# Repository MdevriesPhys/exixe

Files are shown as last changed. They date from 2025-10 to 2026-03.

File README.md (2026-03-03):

# exixe: Low-cost miniature Nixie tube driver modules

[Get exixe](https://www.tindie.com/products/dekuNukem/exixe-miniture-nixie-tube-driver-modules/) | [User manual](getting_started.md)









Forked from original dekuNukem repo, some modifications to boards and firmware.

exixe is a miniature driver module for IN-12 and IN-14 Nixie tubes.

It aims to simplify Nixie tube related projects by eliminating the need for obscure vintage driver chips and multiplexing circuits. Instead, you can control every digit and the RGB backlight via SPI using only 3 wires and 1 line of code.

exixe is cheap, small and modular for easy integration. It is compatible with Arduino, Raspberry Pi, and virtually all embedded dev boards today.

## Updated firmware 2026-03-03
Original firmware for IN-14 boards had an issue where the LEDs would be slightly on when set to 0 brightness. This has been updating in exixie14.hex firmware. See [Getting started](getting_started.md) for information about reflashing.

## Buy exixe on Tindie!

I did a small production run of exixe modules, and now you can buy them directly on Tindie:

https://www.tindie.com/products/dekuNukem/exixe-miniture-nixie-tube-driver-modules/

## Features

Compared to the traditional approach, exixe modules offers significant advantages:

#### Small and modular
* 2x4 cm (0.79x1.57 inches)
* Breadboard friendly
* Easy integration
* Reusable

#### SPI interface
* High speed, up to 24MHz SCLK
* Simple 16-byte command packet
* Available on virtually all embedded systems including Arduino and Raspberry Pi

#### Advanced control
* RGB backlight
* 128 brightness levels
* Hardware PWM on all cathodes and LEDs for smooth dimming and animations

#### Tube overdrive
* Optionally allows twice the cathode current
* For poisoned cathodes in second-hand tubes
* [Before](resources/no_overdrive.jpg) and [after](resources/with_overdrive.jpg).

#### No multiplexing
* Brighter display
* Longer tube life
* Simpler design
* Lower power consumption

## Getting started

Please see [getting_started.md](/getting_started.md)

## Arduino Library

Please [click here](arduino_library)

## Raspberry Pi/Python Library

Please [click here](python_library)

## Pinout, SPI command format and technical details

Please see [technical_details.md](/technical_details.md)

## Supported tubes

exixe-14 module is primarily designed for IN-14 Nixie tubes, but will also work with IN-16 and IN-19 tubes. IN-19 specific board in development.

exixe-12 module is primarily designed for IN-12 Nixie tubes, but works with IN-15 tubes as well.

## Using other tubes

You can also use exixe module with unsupported tubes, with some modification.

Please see [unsupported_tubes.md](/unsupported_tubes.md)

## Making some yourself

Please see [making_some.md](/making_some.md)

## Contact

Questions? Feel free to [open an issue](https://github.com/dekuNukem/exixe/issues). This is the preferred way since it helps other people too.

You can also email me at `dekunukem gmail com` for inquires.

## More photos

exixe-12 working with an Arduino Micro, showing a smooth crossfade animation:



exixe-14 in action on a [finished clock](https://github.com/dekuNukem/exixe_clock):





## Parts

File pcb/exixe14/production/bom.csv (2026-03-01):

Designator | Footprint | Quantity | Value | LCSC Part #
C1, C2, C3 | 0805 | 3 | 100n
D1 | LED_RGB_Wuerth-PLCC4_3.2x2.8mm_150141M173100 | 1 | LED_ABRG
J1, J2 | PinHeader_1x07_P2.54mm_Vertical | 2 | Conn_01x07
N1 | IN-14 | 1 | IN-14
Q1 | SOT-323_SC-70 | 1 | Q_PNP_BEC
Q10, Q11, Q12, Q13, Q14, Q2, Q3, Q4, Q5, Q6, Q7, Q8, Q9 | SOT-323_SC-70 | 13 | Q_NPN_BEC
R1, R10, R14, R15, R16, R17, R18, R19, R2, R20, R21, R22, R23, R24, R25, R5, R7, R8 | 0805 | 18 | 10k
R11, R3 | 0805 | 2 | 68k
R12 | 0805 | 1 | 680R
R13, R9 | 0805 | 2 | 330R
R4, R6 | 0805 | 2 | 1M
U1 | LQFP-32_7x7mm_P0.8mm | 1 | STM32F042K6Tx

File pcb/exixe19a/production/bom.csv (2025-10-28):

Designator | Footprint | Quantity | Value | LCSC Part #
C1, C2, C3 | 0805 | 3 | 100n
D1 | LED_RGB_Wuerth-PLCC4_3.2x2.8mm_150141M173100 | 1 | LED_ABRG
Q1, Q10, Q11, Q4, Q5, Q6, Q7, Q8, Q9 | SOT-323_SC-70 | 9 | BF820W
Q3 | SOT-323_SC-70 | 1 | MSB92W
R1, R13, R14, R15, R16, R17, R18, R19, R2, R20, R21, R3, R4, R5 | 0805 | 14 | 10k
R10 | 0805 | 1 | 680R
R11, R12 | 0805 | 2 | 330R
R6, R7 | 0805 | 2 | 1M
R8, R9 | 0805 | 2 | 68k
U1 | TQFP-32_7x7mm_P0.8mm | 1 | STM32F042K6

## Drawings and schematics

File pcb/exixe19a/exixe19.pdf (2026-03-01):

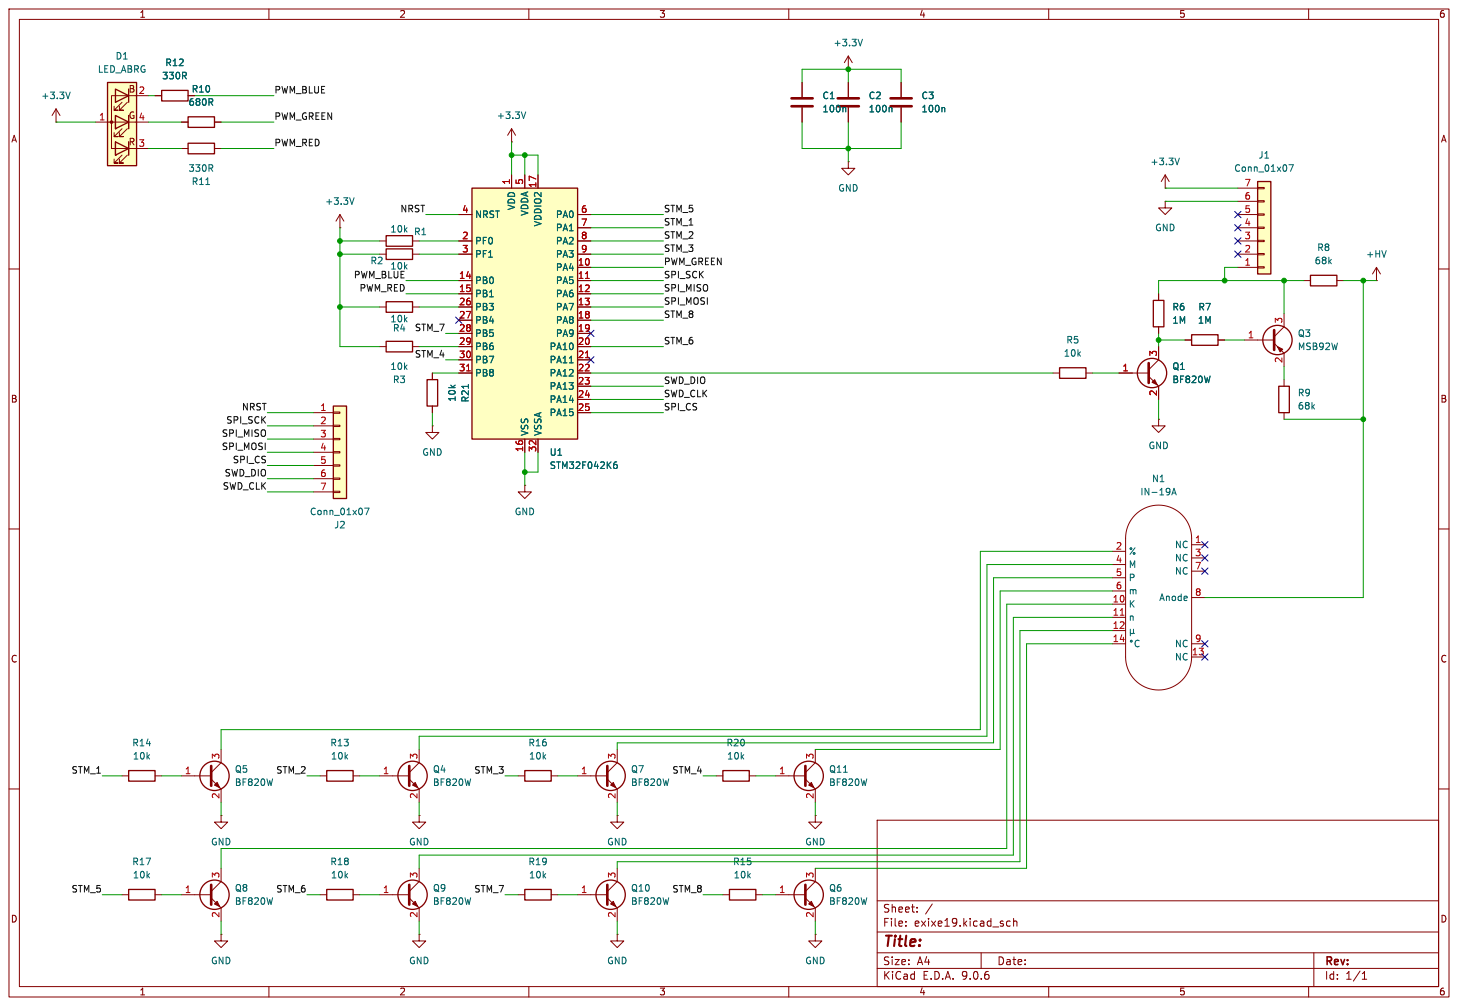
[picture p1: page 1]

Id: 1/1 Title: File: exixe19.kicad_sch Sheet: / 1

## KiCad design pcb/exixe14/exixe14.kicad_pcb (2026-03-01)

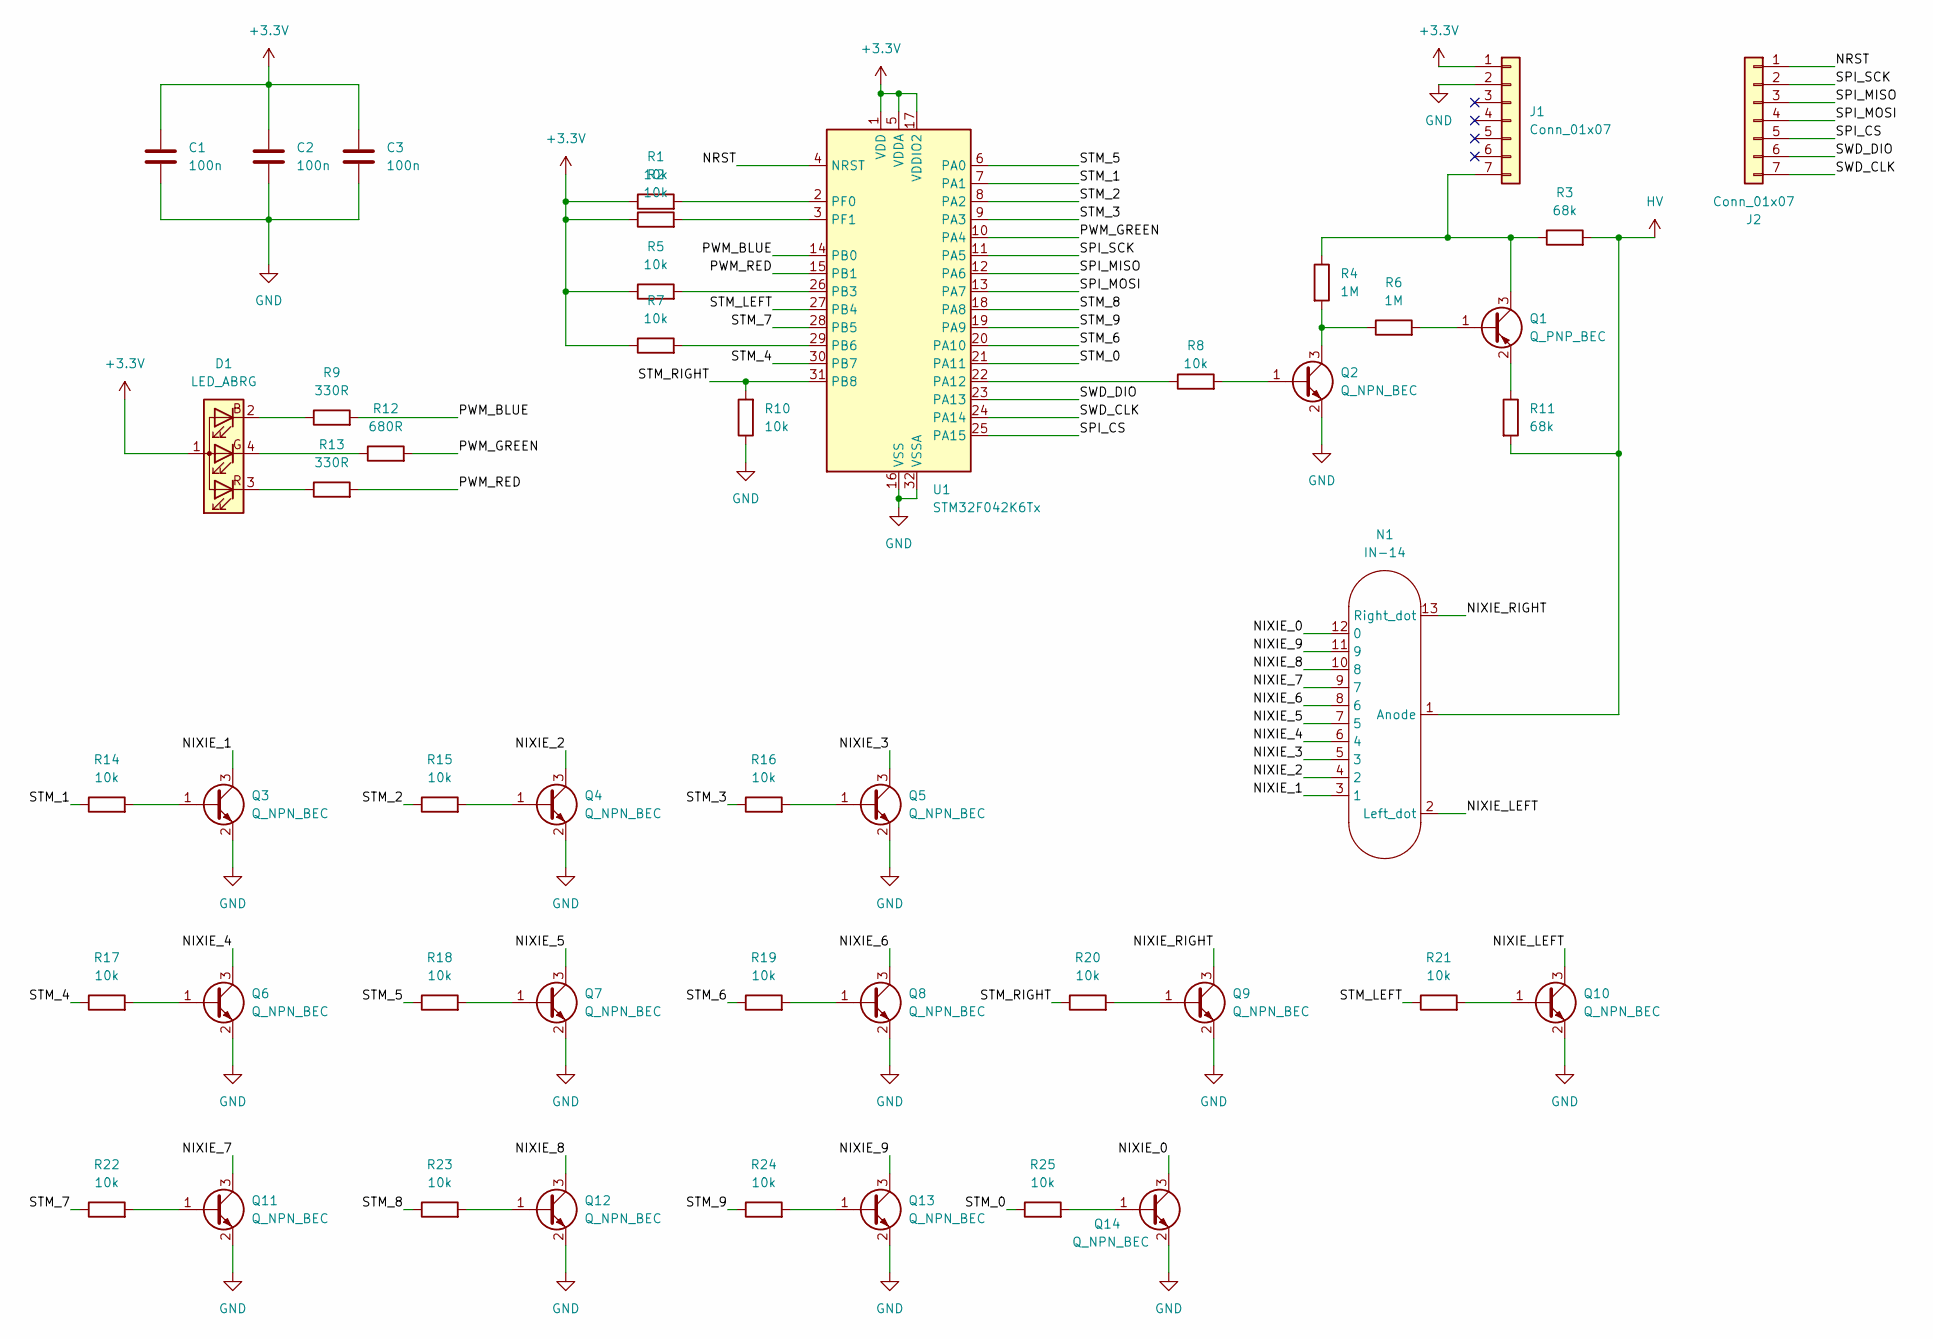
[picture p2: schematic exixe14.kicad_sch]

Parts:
C1, C2, C3: 100n; C_0805_2012Metric
D1: LED_ABRG; LED_RGB_Wuerth-PLCC4_3.2x2.8mm_150141M173100
J1, J2: Conn_01x07; PinHeader_1x07_P2.54mm_Vertical
N1: IN-14
Q1: Q_PNP_BEC; SOT-323_SC-70
Q2, Q3, Q4, Q5, Q6, Q7, Q8, Q9, Q10, Q11, Q12, Q13, Q14: Q_NPN_BEC; SOT-323_SC-70
R1, R2, R5, R7, R8, R10, R14, R15, R16, R17, R18, R19, R20, R21, R22, R23, R24, R25: 10k; R_0805_2012Metric
R3, R11: 68k; R_0805_2012Metric
R4, R6: 1M; R_0805_2012Metric
R9, R13: 330R; R_0805_2012Metric
R12: 680R; R_0805_2012Metric
U1: STM32F042K6Tx; LQFP-32_7x7mm_P0.8mm

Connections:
+3.3V: C1.1, C2.1, C3.1, D1.1 (A), J1.1, R1.1, R2.1, R5.1, R7.1, U1.1 (VDD), U1.5 (VDDA), U1.17 (VDDIO2)
/NIXIE_0: N1.12 (0), Q14.3 (C)
/NIXIE_1: N1.3 (1), Q3.3 (C)
/NIXIE_2: N1.4 (2), Q4.3 (C)
/NIXIE_3: N1.5 (3), Q5.3 (C)
/NIXIE_4: N1.6 (4), Q6.3 (C)
/NIXIE_5: N1.7 (5), Q7.3 (C)
/NIXIE_6: N1.8 (6), Q8.3 (C)
/NIXIE_7: N1.9 (7), Q11.3 (C)
/NIXIE_8: N1.10 (8), Q12.3 (C)
/NIXIE_9: N1.11 (9), Q13.3 (C)
/NIXIE_LEFT: N1.2 (Left_dot), Q10.3 (C)
/NIXIE_RIGHT: N1.13 (Right_dot), Q9.3 (C)
/NRST: J2.1, U1.4 (NRST)
/PWM_BLUE: R9.2, U1.14 (PB0)
/PWM_GREEN: R12.2, U1.10 (PA4)
/PWM_RED: R13.2, U1.15 (PB1)
/SPI_CS: J2.5, U1.25 (PA15)
/SPI_MISO: J2.3, U1.12 (PA6)
/SPI_MOSI: J2.4, U1.13 (PA7)
/SPI_SCK: J2.2, U1.11 (PA5)
/STM_0: R25.1, U1.21 (PA11)
/STM_1: R14.1, U1.7 (PA1)
/STM_2: R15.1, U1.8 (PA2)
/STM_3: R16.1, U1.9 (PA3)
/STM_4: R17.1, U1.30 (PB7)
/STM_5: R18.1, U1.6 (PA0)
/STM_6: R19.1, U1.20 (PA10)
/STM_7: R22.1, U1.28 (PB5)
/STM_8: R23.1, U1.18 (PA8)
/STM_9: R24.1, U1.19 (PA9)
/STM_LEFT: R21.1, U1.27 (PB4)
/STM_RIGHT: R10.2, R20.1, U1.31 (PB8)
/SWD_CLK: J2.7, U1.24 (PA14)
/SWD_DIO: J2.6, U1.23 (PA13)
GND: C1.2, C2.2, C3.2, J1.2, Q2.2 (E), Q3.2 (E), Q4.2 (E), Q5.2 (E), Q6.2 (E), Q7.2 (E), Q8.2 (E), Q9.2 (E), Q10.2 (E), Q11.2 (E), Q12.2 (E), Q13.2 (E), Q14.2 (E), R10.1, U1.16 (VSS), U1.32 (VSSA)
HV: N1.1 (Anode), R3.2, R11.2
unnamed: D1.2 (BK), R9.1
unnamed: D1.4 (GK), R12.1
unnamed: D1.3 (RK), R13.1
unnamed: J1.7, Q1.3 (C), R3.1, R4.1
unnamed: Q1.1 (B), R6.2
unnamed: Q1.2 (E), R11.1
unnamed: Q2.1 (B), R8.2
unnamed: Q2.3 (C), R4.2, R6.1
unnamed: Q3.1 (B), R14.2
unnamed: Q4.1 (B), R15.2
unnamed: Q5.1 (B), R16.2
unnamed: Q6.1 (B), R17.2
unnamed: Q7.1 (B), R18.2
unnamed: Q8.1 (B), R19.2
unnamed: Q9.1 (B), R20.2
unnamed: Q10.1 (B), R21.2
unnamed: Q11.1 (B), R22.2
unnamed: Q12.1 (B), R23.2
unnamed: Q13.1 (B), R24.2
unnamed: Q14.1 (B), R25.2
unnamed: R8.1, U1.22 (PA12)
unnamed: R5.2, U1.26 (PB3)
unnamed: R7.2, U1.29 (PB6)
unnamed: R1.2, U1.2 (PF0)
unnamed: R2.2, U1.3 (PF1)

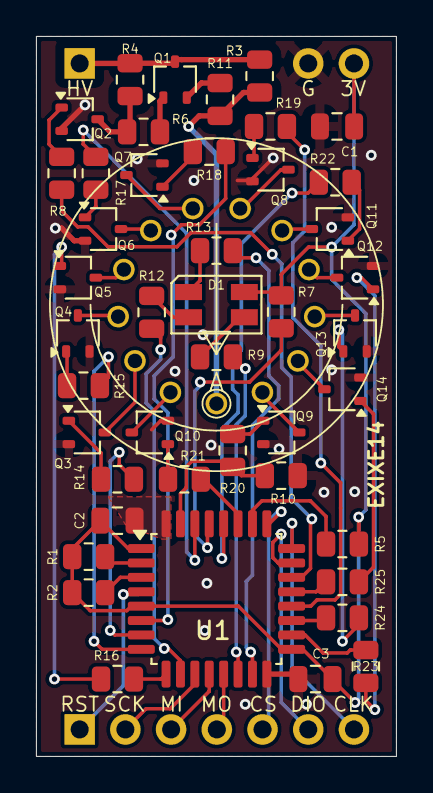
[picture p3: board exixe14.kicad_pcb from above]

Board: 2 copper layers, 20.0 x 40.0 mm, 47 parts (0 on the bottom side), 62 nets.

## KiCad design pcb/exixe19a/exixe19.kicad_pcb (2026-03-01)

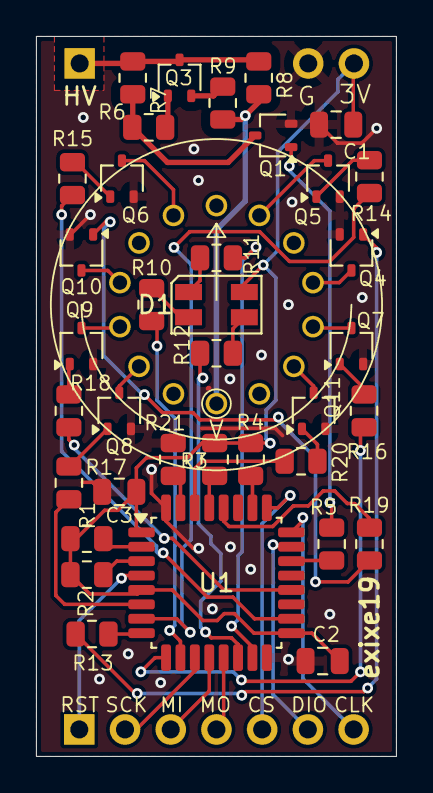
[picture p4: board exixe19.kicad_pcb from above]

Board: 2 copper layers, 20.0 x 40.0 mm, 39 parts (0 on the bottom side), 51 nets.

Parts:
C1, C2, C3: 100n; C_0805_2012Metric
D1: LED_ABRG; LED_RGB_Wuerth-PLCC4_3.2x2.8mm_150141M173100
J1: Conn_01x07; PinHeader_1x07_P2.54mm_Vertical_special
J2: Conn_01x07; PinHeader_1x07_P2.54mm_Vertical
N1: IN-19A
Q1, Q4, Q5, Q6, Q7, Q8, Q9, Q10, Q11: BF820W; SOT-323_SC-70
Q3: MSB92W; SOT-323_SC-70
R1, R2, R3, R4, R5, R13, R14, R15, R16, R17, R18, R19, R20, R21: 10k; R_0805_2012Metric
R6, R7: 1M; R_0805_2012Metric
R8, R9: 68k; R_0805_2012Metric
R10: 680R; R_0805_2012Metric
R11, R12: 330R; R_0805_2012Metric
U1: STM32F042K6; TQFP-32_7x7mm_P0.8mm

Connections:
+3.3V: C1.1, C2.1, C3.1, D1.1 (A), J1.7, R1.1, R2.1, R3.1, R4.1, U1.1 (VDD), U1.5 (VDDA), U1.17 (VDDIO2)
+HV: N1.8 (Anode), R8.1, R9.1
/NRST: J2.1, U1.4 (NRST)
/PWM_BLUE: R12.2, U1.14 (PB0)
/PWM_GREEN: R10.2, U1.10 (PA4)
/PWM_RED: R11.2, U1.15 (PB1)
/SPI_CS: J2.5, U1.25 (PA15)
/SPI_MISO: J2.3, U1.12 (PA6)
/SPI_MOSI: J2.4, U1.13 (PA7)
/SPI_SCK: J2.2, U1.11 (PA5)
/STM_1: R14.1, U1.7 (PA1)
/STM_2: R13.1, U1.8 (PA2)
/STM_3: R16.1, U1.9 (PA3)
/STM_4: R20.1, U1.30 (PB7)
/STM_5: R17.1, U1.6 (PA0)
/STM_6: R18.1, U1.20 (PA10)
/STM_7: R19.1, U1.28 (PB5)
/STM_8: R15.1, U1.18 (PA8)
/SWD_CLK: J2.7, U1.24 (PA14)
/SWD_DIO: J2.6, U1.23 (PA13)
GND: C1.2, C2.2, C3.2, J1.6, Q1.2 (E), Q4.2 (E), Q5.2 (E), Q6.2 (E), Q7.2 (E), Q8.2 (E), Q9.2 (E), Q10.2 (E), Q11.2 (E), R21.1, U1.16 (VSS), U1.32 (VSSA)
unnamed: D1.2 (BK), R12.1
unnamed: D1.4 (GK), R10.1
unnamed: D1.3 (RK), R11.1
unnamed: J1.1, Q3.3 (C), R6.1, R8.2
unnamed: N1.2 (%), Q5.3 (C)
unnamed: N1.10 (K), Q8.3 (C)
unnamed: N1.4 (M), Q4.3 (C)
unnamed: N1.5, Q7.3 (C)
unnamed: N1.6 (m), Q11.3 (C)
unnamed: N1.11 (n), Q9.3 (C)
unnamed: N1.14 (°С), Q6.3 (C)
unnamed: N1.12 (µ), Q10.3 (C)
unnamed: Q1.1 (B), R5.2
unnamed: Q1.3 (C), R6.2, R7.1
unnamed: Q3.1 (B), R7.2
unnamed: Q3.2 (E), R9.2
unnamed: Q4.1 (B), R13.2
unnamed: Q5.1 (B), R14.2
unnamed: Q6.1 (B), R15.2
unnamed: Q7.1 (B), R16.2
unnamed: Q8.1 (B), R17.2
unnamed: Q9.1 (B), R18.2
unnamed: Q10.1 (B), R19.2
unnamed: Q11.1 (B), R20.2
unnamed: R5.1, U1.22 (PA12)
unnamed: R4.2, U1.26 (PB3)
unnamed: R3.2, U1.29 (PB6)
unnamed: R21.2, U1.31 (PB8)
unnamed: R1.2, U1.2 (PF0)
unnamed: R2.2, U1.3 (PF1)

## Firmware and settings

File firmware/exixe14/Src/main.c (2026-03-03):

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
/* Includes ------------------------------------------------------------------*/
#include "main.h"

/* USER CODE BEGIN Includes */
#include "shared.h"
#include "helpers.h"
#include <stdio.h>

/* USER CODE END Includes */

IWDG_HandleTypeDef hiwdg;

SPI_HandleTypeDef hspi1;
DMA_HandleTypeDef hdma_spi1_rx;

TIM_HandleTypeDef htim1;
TIM_HandleTypeDef htim2;
TIM_HandleTypeDef htim3;
TIM_HandleTypeDef htim14;
TIM_HandleTypeDef htim16;
TIM_HandleTypeDef htim17;

UART_HandleTypeDef huart1;

/* USER CODE BEGIN PV */

/* USER CODE END PV */

void SystemClock_Config(void);
static void MX_GPIO_Init(void);
static void MX_DMA_Init(void);
static void MX_IWDG_Init(void);
static void MX_SPI1_Init(void);
static void MX_TIM1_Init(void);
static void MX_TIM2_Init(void);
static void MX_TIM3_Init(void);
static void MX_TIM14_Init(void);
static void MX_TIM16_Init(void);
static void MX_TIM17_Init(void);
static void MX_USART1_UART_Init(void);
/* USER CODE BEGIN PFP */
/* USER CODE END PFP */

/* USER CODE BEGIN 0 */
int fputc(int ch, FILE *f)
{
    HAL_UART_Transmit(&huart1, (unsigned char *)&ch, 1, 100);
    return ch;
}
/* USER CODE END 0 */

/**
  * @brief  The application entry point.
  * @retval int
  */
int main(void)
{

  /* MCU Configuration--------------------------------------------------------*/

  /* Reset of all peripherals, Initializes the Flash interface and the Systick. */
  HAL_Init();

  /* Configure the system clock */
  SystemClock_Config();

  /* Initialize all configured peripherals */
  MX_GPIO_Init();
  MX_DMA_Init();
  MX_IWDG_Init();
  MX_SPI1_Init();
  MX_TIM1_Init();
  MX_TIM2_Init();
  MX_TIM3_Init();
  MX_TIM14_Init();
  MX_TIM16_Init();
  MX_TIM17_Init();
  MX_USART1_UART_Init();
  /* Infinite loop */
  /* USER CODE BEGIN WHILE */
  timer_init();
  HAL_Delay(10);
  while(1)
  {
    HAL_IWDG_Refresh(&hiwdg);
    if(HAL_GPIO_ReadPin(GPIOA, GPIO_PIN_15) == GPIO_PIN_SET)
      HAL_SPI_Receive_DMA(&hspi1, spi_recv_buf, SPI_BUF_SIZE);
    /* USER CODE END WHILE */

    /* USER CODE BEGIN 3 */
  }
  /* USER CODE END 3 */
}

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
/* USER CODE BEGIN 4 */
void HAL_SPI_RxCpltCallback(SPI_HandleTypeDef *hspi)
{
  if((spi_recv_buf[0] & 0xfe) != SPI_CMD_UPDATE)
    HAL_NVIC_SystemReset();
  set_pwm(spi_recv_buf);
  if(spi_recv_buf[0] & 0x1)
      HAL_GPIO_WritePin(BAKE_GPIO_Port, BAKE_Pin, GPIO_PIN_SET);
  else
      HAL_GPIO_WritePin(BAKE_GPIO_Port, BAKE_Pin, GPIO_PIN_RESET);
  HAL_SPI_Receive_DMA(&hspi1, spi_recv_buf, SPI_BUF_SIZE);
}

/* USER CODE END 4 */
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


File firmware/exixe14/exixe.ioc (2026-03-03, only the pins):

Mcu.UserName=STM32F042K6Tx
PA0.Signal=S_TIM2_CH1_ETR
PA1.Signal=S_TIM2_CH2
PA10.Signal=S_TIM1_CH3
PA11.Signal=S_TIM1_CH4
PA12.GPIO_Label=BAKE
PA12.Signal=GPIO_Output
PA13.Signal=SYS_SWDIO
PA14.Signal=SYS_SWCLK
PA15.Signal=SPI1_NSS
PA2.Signal=S_TIM2_CH3
PA3.Signal=S_TIM2_CH4
PA4.Signal=S_TIM14_CH1
PA5.Signal=SPI1_SCK
PA6.Signal=SPI1_MISO
PA7.Signal=SPI1_MOSI
PA8.Signal=S_TIM1_CH1
PA9.Signal=S_TIM1_CH2
PB0.Signal=S_TIM3_CH3
PB1.Signal=S_TIM3_CH4
PB4.Signal=S_TIM3_CH1
PB5.Signal=S_TIM3_CH2
PB6.Signal=USART1_TX
PB7.Signal=TIM17_CH1N
PB8.Signal=S_TIM16_CH1

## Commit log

2025-10-02 IN-19A PCB design started
    [exixe19a.kicad_pcb, exixe19a.kicad_sch]
2025-10-14 pcb design for IN-19 tubes
    [exixe19.stl, exixe19a.kicad_pcb, exixe19a.kicad_sch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]
2025-10-15 updated exixe19a pcb
    [exixe19.stl, exixe19a.kicad_pcb, exixe19a.kicad_sch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]
2025-10-28 trying to do firmware
    [bom.csv, designators.csv, exixe19a.kicad_pcb_bom.csv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]
2026-01-09 Turns out I need to watch out for grounding planes that aren't actually connected to anything
    [exixe19a.kicad_pcb, exixe19a.kicad_pcb_bom.csv, exixe19a.kicad_pcb_positions.csv]
2026-01-09 new version should work
    [exixe19a.kicad_pcb, exixe19a.kicad_pcb_bom.csv, exixe19a.kicad_pcb_positions.csv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]
2026-01-13 updated layout, made new version of exixe14 schematic
    [bom.csv, designators.csv, exixe14.kicad_pcb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]
2026-01-15 Tidied up IN-19, started update to IN-14 board
    [exixe14.brd, exixe14.kicad_pcb, exixe14.kicad_sch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]
2026-01-27 updating exixe14 pcb
    [exixe14.kicad_pcb]
2026-02-01 pcb layout is hard
    [exixe14.kicad_pcb]
2026-02-18 working on exixe14 pcb
    [exixe14.kicad_pcb]
2026-02-18 layout is hard
    [exixe14.kicad_pcb]
2026-02-20 This layout looks okay?
    [exixe14.kicad_pcb]
2026-03-01 attempt to correct firmware to remove glowing led issue
    [bom.csv, designators.csv, exixe14.kicad_pcb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]
2026-03-02 LED fix check, helps if I actually make the .hex...
2026-03-03 Update to exixie14 firmware, the LEDs will now be off when set to (0,0,0)

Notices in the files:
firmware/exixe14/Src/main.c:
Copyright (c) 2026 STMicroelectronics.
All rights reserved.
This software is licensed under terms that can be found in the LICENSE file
